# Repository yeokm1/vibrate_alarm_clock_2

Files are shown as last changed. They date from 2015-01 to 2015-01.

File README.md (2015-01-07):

vibrate_alarm_clock_2
===================

An alarm clock with vibration, battery monitoring and induction (wireless) charging capabilities.  Buttons available to set the time/alarm, turn off OLED and reset. This device is meant for my friend's birthday gift. 

As you can tell from the name, this is the second version. It has been slightly streamlined compared to the [first](https://github.com/yeokm1/vibrate_alarm_clock).

##Demo video on Youtube
(http://www.youtube.com/watch?v=rJnRN-2LL7Q)

##Final pictures
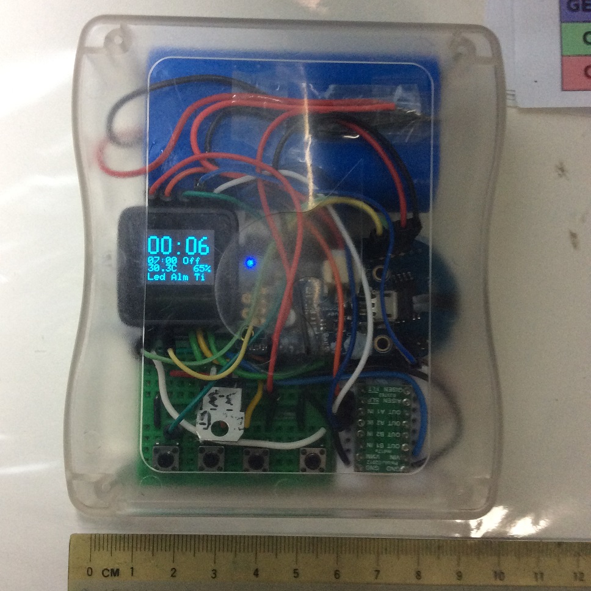
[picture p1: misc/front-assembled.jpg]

Front, fully assembled.

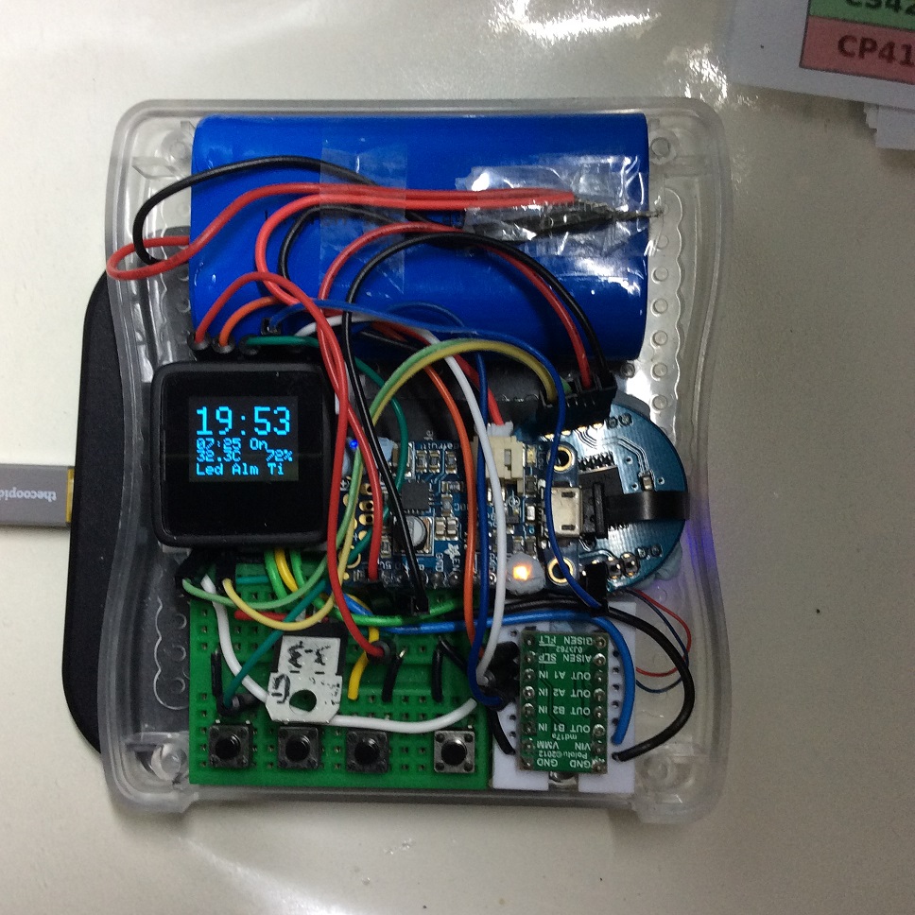
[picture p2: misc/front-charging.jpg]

Top cover removed and charging on my Qi wireless charge pad.

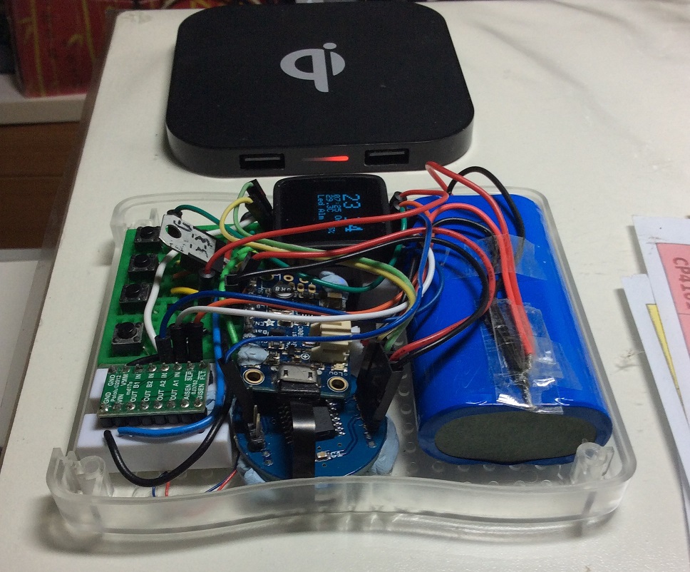
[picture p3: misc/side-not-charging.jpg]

Side view with top open. A Qi wireless charger in the background. Not so messy this time.

<b>More pictures during the assembly/testing phase at the end.</b>

##Parts used
1. [Microview](https://www.sparkfun.com/products/12923) with 64x48 OLED screen (based on ATmega328P chip). Bought during its Kickstarter [campaign](https://www.kickstarter.com/projects/1516846343/microview-chip-sized-arduino-with-built-in-oled-di).
2. [Chronodot](http://docs.macetech.com/doku.php/chronodot_v2.0) v2.1 Real Time Clock (based on DS3231 temperature compensated RTC crystal)
3. [Adafruit PowerBoost 500 Charger](https://learn.adafruit.com/adafruit-powerboost-500-plus-charger/overview)
4. 3.3V voltage regulator (LD1117V33)
5. 4x button switches (1 switch as reset button)  
6. [Pololu DRV8833](http://www.pololu.com/product/2130) dual motor driver  
7. 500mA Qi wireless receiver module
8. 10mm vibration motor
9. 4400mAh Lithium battery

Others:  

1. 1x half-breadboard 
2. 4x mini-breadboard (2x8 points)
3. Translucent case  

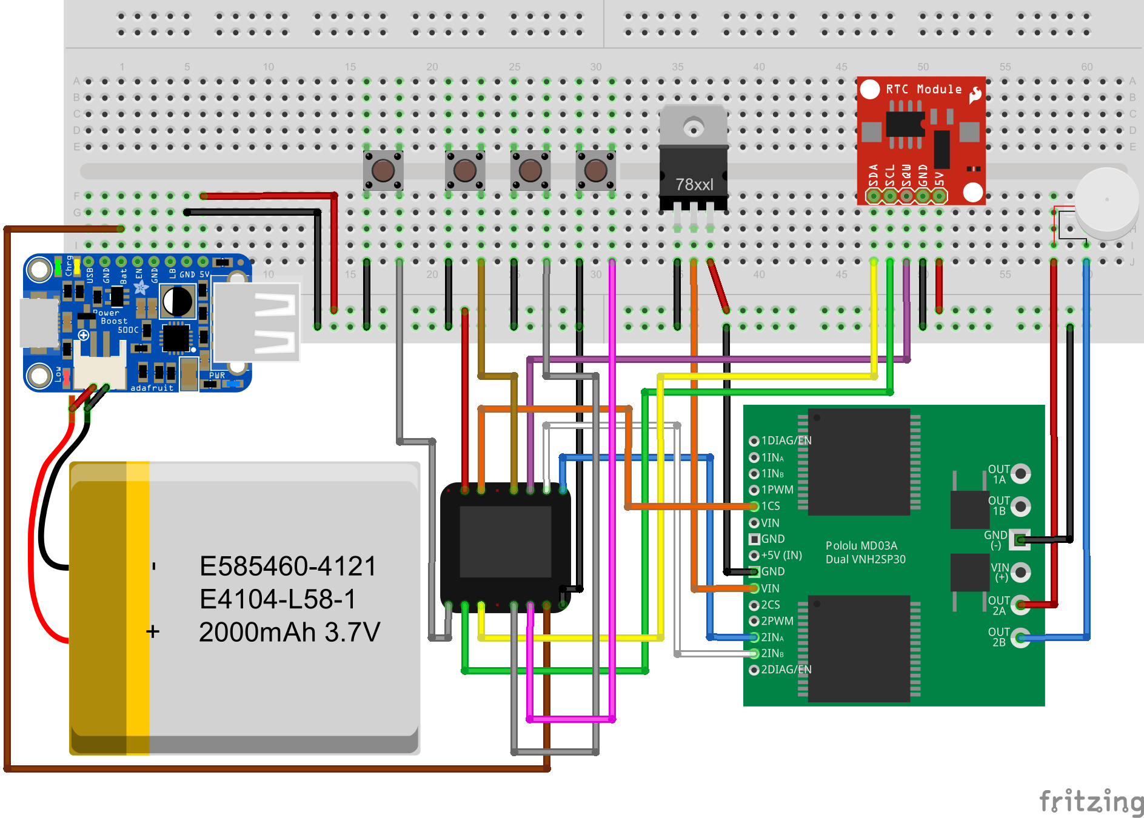
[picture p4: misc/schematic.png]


This schematic only represents the logical connections I made. The physical connections differs due to space issues.
Closest components used as Fritzing does not have them.

1. MD030A as DRV8833 motor driver. (Pin 6 on the Microview is connected to the sleep pin on the DRV8833.)
2. RTC module as Chronodot
3. The battery is a cylindrical style 4400mAh one.

##Differences with [version 1 (V1)](https://github.com/yeokm1/vibrate_alarm_clock)
1. No more pull-down resistors for the switches. I use the internal pull-up resistors of the Arduino by setting pinmode to INPUT_PULLUP.
2. Battery capacity: The battery size was an afterthought in V1. The battery size is now more than 4x larger.
3. Power consumption: Reduced by putting the Arduino to sleep and only waking via alarm interrupts from the Chronodot or button press. Even if alarm is enabled, current use is 34mA with display on and 16mA when in sleep giving battery life at approximately 5 and 11 days respectively. (See pictures below)
4. The components here now run at 5V levels instead of 3.3V previously as that is the output of the PowerBoost charger even though this may not be entirely efficient. I can't use the battery output directly as that value can drop below 3.3V.
5. The Pololu DRV8833 motor driver is powered behind a 3.3V regulator as 5V is too high for the 10mm vibration motor.
6. Display the temperature of the Chronodot.
7. Qi wireless charging. Frequent plugging in and out of the micro-USB cable may wear-out/damage the connector. Wireless charging is convenient too!
8. Removed speaker as it is rather soft. Even the vibration motor is louder than the speaker!

##Notes
1. The Analog to Digital Converter (ADC) of the Microview is rather unstable. As the battery voltage is retrieved via the ADC, I had to do a running average to get a stable value to display.

##Pictures during assembly/testing
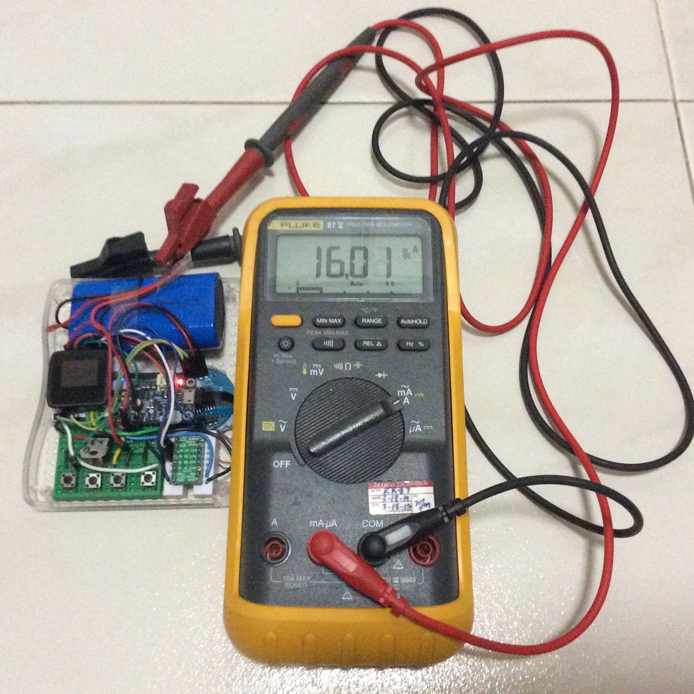
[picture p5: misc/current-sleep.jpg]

Current while in sleep mode. Hardware folks may say I can do better but I don't really have time to optimise so much.

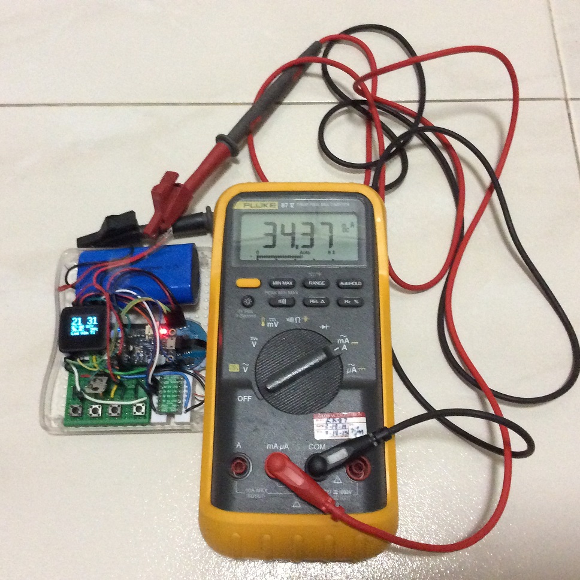
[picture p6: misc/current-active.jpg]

Current with screen on and no sleep. Current usage more than doubles.

Screen
Side profile. Obviously not charging at such distance away.

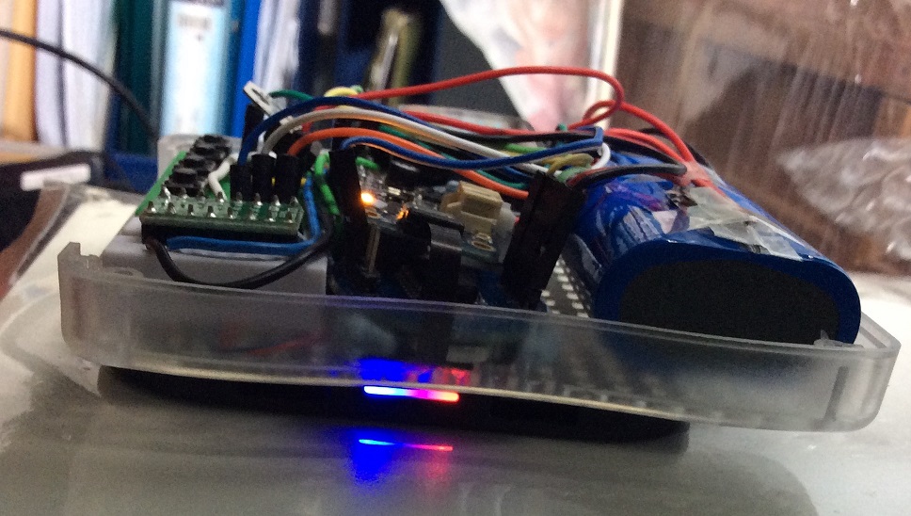
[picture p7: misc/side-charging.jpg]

On my Qi wireless charge pad. Blue light on the Qi pad and orange on the PowerBoost charger indicates a successful power transfer process.

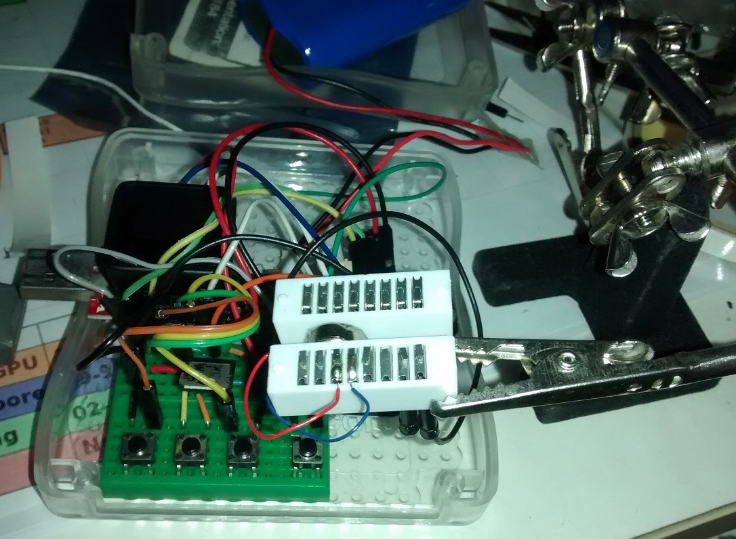
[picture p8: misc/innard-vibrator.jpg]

Under the motor driver is where I "hide" the vibrator to prevent it from jumping out of place as experienced in V1.

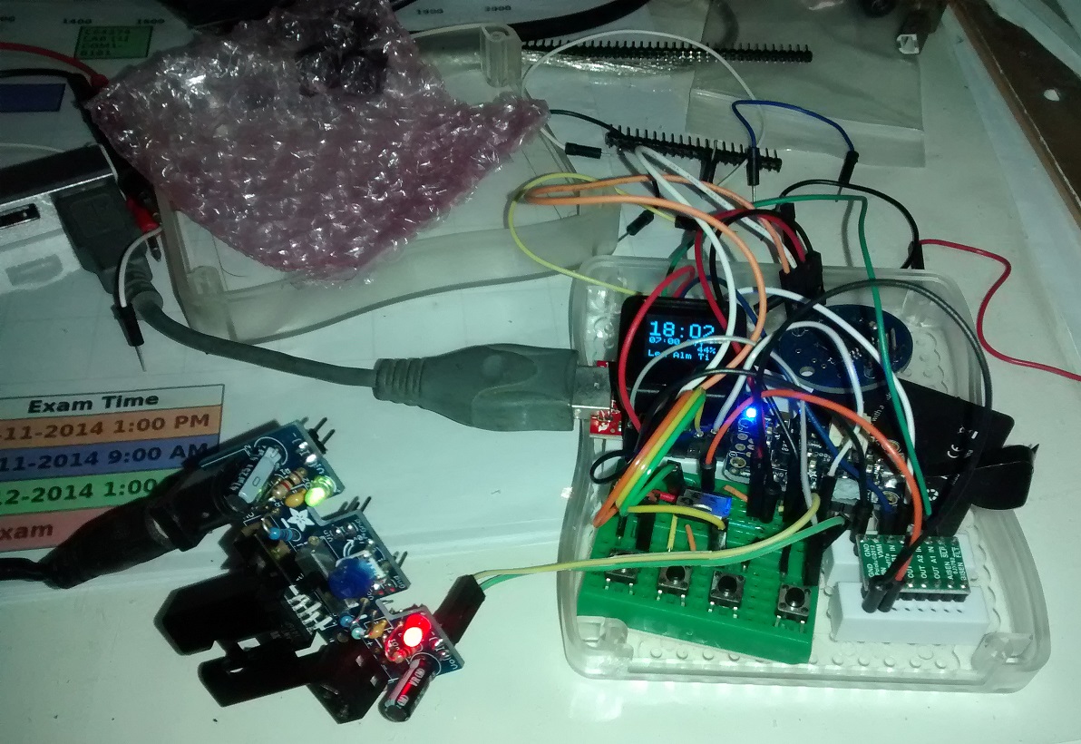
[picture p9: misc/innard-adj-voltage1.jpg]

I use the very nifty [adjustable voltage generator](https://learn.adafruit.com/adjustable-breadboard-power-supply-kit) to simulate a battery at different voltage levels to verify the battery percent readings.

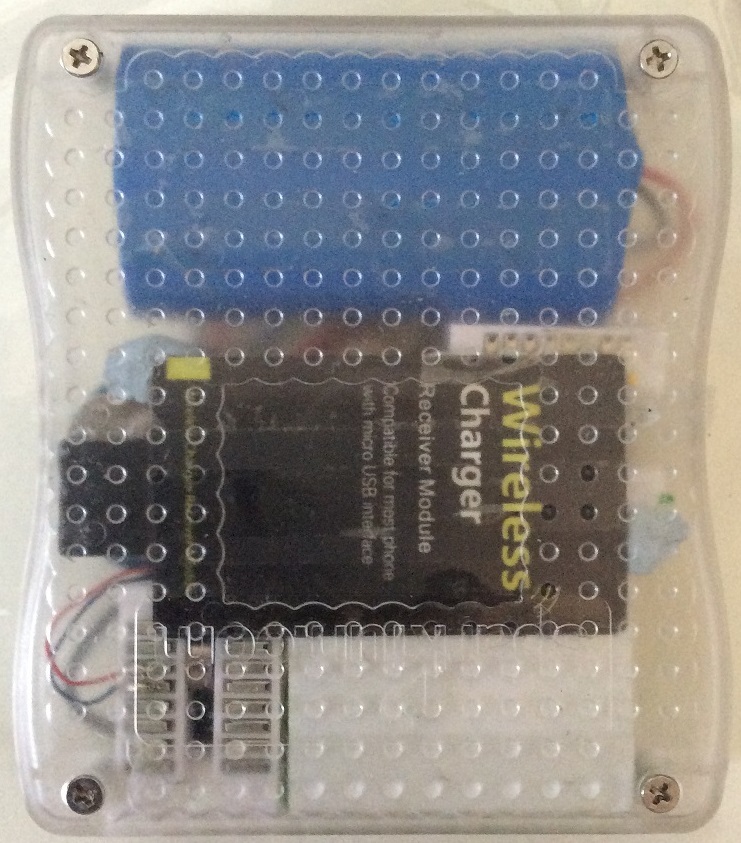
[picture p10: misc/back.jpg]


Adding a wireless power receiving capability is just as simple as adding a receiver pad. Why didn't I consider this earlier?

##References and libraries
1. [Creating fonts for Microview](http://learn.microview.io/font/creating-fonts-for-microview.html)
2. [DS3232 RTC library](https://github.com/JChristensen/DS3232RTC)
3. [Rocketscream Low Power library](http://www.rocketscream.com/blog/2011/07/04/lightweight-low-power-arduino-library/)

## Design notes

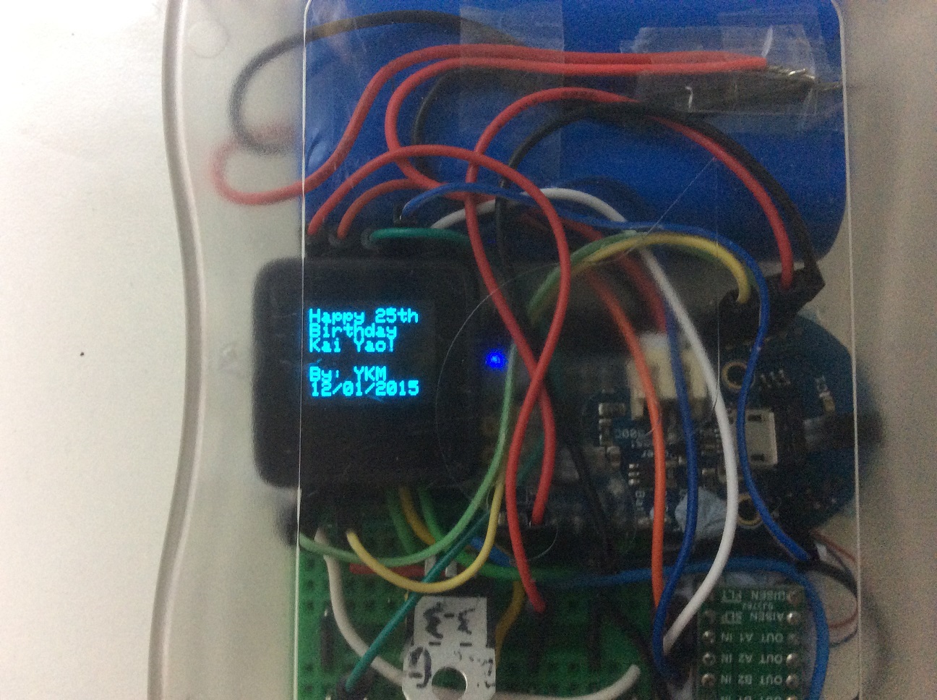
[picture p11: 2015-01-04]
misc/birthday.jpg

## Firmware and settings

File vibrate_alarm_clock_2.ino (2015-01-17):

#include <Wire.h>
#include <MicroView.h>
#include <DS3232RTC.h>
#include <Time.h>

#include "LowPower.h"

//These two refer to the same pin
#define LEFT_BUTTON_INT_PIN INT1
#define LEFT_BUTTON_NORM_PIN 3

#define MIDDLE_BUTTON_PIN A2
#define RIGHT_BUTTON_PIN A1

//These two refer to the same pin
#define ALARM_INT_PIN INT0//Driven LOW by Chronodot on alarm triggered
#define ALARM_NORM_PIN 2//Driven LOW by Chronodot on alarm triggered

#define VOLTAGE_MEASURE_PIN A0

#define MOTOR_PIN1 1
#define MOTOR_PIN2 0
#define MOTOR_SLEEP_PIN 6

#define ADC_PRECISION 1024

//You may need to calibrate these values. My values are based on this data sheet http://www.adafruit.com/datasheets/18650%204400mAh.pdf
#define MIN_BATTERY_MILLIVOLT 3100 //Discharge cut-off voltage is 2750 but I set it higher as repeated discharge to this low will reduce battery lifespan
#define MAX_BATTERY_MILLIVOLT 4200 //Max cell voltage

#define MIN_TIME_BETWEEN_BUTTON_PRESSES 150  //Debouncing purposes

#define MAX_ALARM_LENGTH 600000 //Alarm rings for 10 minutes max


#define BLINK_INTERVAL_SETTINGS 100
#define BLINK_INTERVAL_SECONDS 500

#define MIN_TIME_BETWEEN_ALARM_STARTS 60000 //60 seconds
#define MIN_TIME_BETWEEN_MOTOR_STATES 500

#define INITIAL_TEXT "Happy 25thBirthday\nKai Yao!\n\nBy: YKM\n12/01/2015"
#define INITIAL_TEXT_DELAY 5000

#define TIME_BEFORE_STANDBY 10000 //10s

typedef enum {
  NORMAL, ALARM, SETTING_TIME, SETTING_ALARM} 
CLOCK_STATE ;
volatile CLOCK_STATE currentState = NORMAL;

typedef enum {
  T_HOUR, T_MINUTE, T_VOLTAGE} 
SETTING_TIME_STATE ;
SETTING_TIME_STATE settingTimeProcess;

typedef enum {
  A_HOUR, A_MINUTE, A_TYPE} 
SETTING_ALARM_STATE ;
SETTING_ALARM_STATE settingAlarmProcess;

int alarmHour = 07;
int alarmMinute = 00;

unsigned long alarmLastStarted;

unsigned long timeLastPressedLeftButton;
unsigned long timeLastPressedMiddleButton;
unsigned long timeLastPressedRightButton;

boolean vibrate = false;
boolean showVoltage = false;

boolean previousBlinkState;
unsigned long previousBlinkTime;

boolean previousSecondsBlinkState;
unsigned long previousSecondsBlinkTime;

volatile boolean showLCD = true;
unsigned long lastVibration;
boolean lastMotorState = false;


const int numReadings = 40;

int percentReadings[numReadings];
int percentIndex = 0;    
long percentTotal = 0; 

int milliVoltReadings[numReadings];
int milliVoltIndex = 0;     
long milliVoltTotal = 0;     

long lastScreenActiveTime = 0;

void setup() {

  Wire.begin();
  //Serial.begin(9600);

  setSyncProvider(RTC.get);

  //Clear prior alarm settings on reload
  RTC.squareWave(SQWAVE_NONE);
  RTC.alarmInterrupt(ALARM_1, false);  
  RTC.alarmInterrupt(ALARM_2, false);



  uView.begin();      // begin of MicroView
  uView.clear(ALL);   // erase hardware memory inside the OLED controller
  uView.contrast(0); //Lowest constrast so not so glaring

  pinMode(LEFT_BUTTON_NORM_PIN, INPUT_PULLUP);
  pinMode(MIDDLE_BUTTON_PIN, INPUT_PULLUP);
  pinMode(RIGHT_BUTTON_PIN, INPUT_PULLUP);

  pinMode(VOLTAGE_MEASURE_PIN, INPUT);

  pinMode(ALARM_NORM_PIN, INPUT_PULLUP);


  pinMode(MOTOR_PIN1, OUTPUT); 
  pinMode(MOTOR_PIN2, OUTPUT);
  pinMode(MOTOR_SLEEP_PIN, OUTPUT);

  motorDriverState(false);

  timeLastPressedLeftButton = 0;
  timeLastPressedMiddleButton = 0;
  timeLastPressedRightButton = 0;

  uView.clear(PAGE); 
  uView.setFontType(0);

  uView.println(INITIAL_TEXT); 

  uView.display();


  delay(INITIAL_TEXT_DELAY);
  attachInterrupt(ALARM_INT_PIN, alarmTriggered, FALLING);
  attachInterrupt(LEFT_BUTTON_INT_PIN, leftButtonIntPressed, FALLING); //Left Button is used to wake up from deep sleep
  
  lastScreenActiveTime = millis();
}

void loop (){


  int leftButtonState = digitalRead(LEFT_BUTTON_NORM_PIN);
  int middleButtonState = digitalRead(MIDDLE_BUTTON_PIN);
  int rightPinState = digitalRead(RIGHT_BUTTON_PIN);


  if(leftButtonState == LOW){
    processLeftButtonPressed();
  }

  if(middleButtonState == LOW){
    processMiddleButtonPressed();
  }

  if(rightPinState == LOW){
    processRightButtonPressed();
  }

  soundAlarmAtThisPointIfNeeded();
  
  long currentTime = millis();

  //Disable alarm if it has gone longer than maximum
  if(currentState == ALARM && (currentTime - alarmLastStarted) > MAX_ALARM_LENGTH){
    stopAlarm();
  }
  
  //Auto turn off screen after certain time
  if(currentState == NORMAL && showLCD && ((currentTime - lastScreenActiveTime) > TIME_BEFORE_STANDBY)){
    showLCD = false;
    turnOffLCDIfCommandIsOff();
  }

  if(showLCD || currentState == ALARM){
    setSyncProvider(RTC.get);

    uView.clear(PAGE);

    boolean blinkOn = shouldBlinkNow();
    boolean secondsBlink = shouldSecondsBlinkNow();

    int voltageADCReading = getVoltageADCReading();

    long vccVoltage = getVcc();
    //Serial.println(vccVoltage);
    int batteryMilliVolt = ((long) voltageADCReading * vccVoltage) / ADC_PRECISION;

    float celsius = RTC.temperature() / 4.0;


    writeTimeToDisplayBuffer(blinkOn, secondsBlink);
    writeAlarmToDisplayBuffer(blinkOn);




    writeVoltageAndTempToDisplayBuffer(batteryMilliVolt, celsius, blinkOn);
    writeButtonStateToDisplayBuffer(blinkOn);


    uView.display();
  }


  if(currentState == NORMAL){   
    if(showLCD){
      LowPower.powerDown(SLEEP_15Ms, ADC_OFF, BOD_OFF);
    }
    else {
      LowPower.powerDown(SLEEP_FOREVER, ADC_OFF, BOD_OFF);
    }

  }


}

int getVoltageADCReading(){
  return analogRead(VOLTAGE_MEASURE_PIN); 
}


void turnOffLCDIfCommandIsOff(){
  if(!showLCD){
    uView.clear(PAGE);
    uView.display();
  }
}

void leftButtonIntPressed(){
  if(!showLCD && currentState == NORMAL){
    showLCD = true;
    long currentTime = millis();
    timeLastPressedLeftButton = currentTime;
    lastScreenActiveTime = currentTime;
  }
}

void processLeftButtonPressed(){
  unsigned long currentMillis = millis();

  if((currentMillis - timeLastPressedLeftButton) < MIN_TIME_BETWEEN_BUTTON_PRESSES){
    return;
  }
  

  timeLastPressedLeftButton = currentMillis;
  lastScreenActiveTime = currentMillis;

  //Serial.println("Left Button Pressed");

  switch(currentState)
  {
  case ALARM: 
    stopAlarm();
    break;
  case NORMAL :
    {
      showLCD = !showLCD;
      turnOffLCDIfCommandIsOff();

    }
    break;
  case SETTING_ALARM:
    {
      if(settingAlarmProcess == A_HOUR){
        alarmHour = getNextHourFromCurrentHour(alarmHour, false);
      } 
      else if(settingAlarmProcess == A_MINUTE){
        alarmMinute = getNextMinSecFromCurrentMinSec(alarmMinute, false);
      } 
      else if(settingAlarmProcess == A_TYPE){
        vibrate = !vibrate;
      }

    }
    break;
  case SETTING_TIME:
    {
      switch(settingTimeProcess){
      case T_HOUR:
        setTime(getNextHourFromCurrentHour(hour(), false), minute(), second(), day(), month(), year());
        break;
      case T_MINUTE:
        setTime(hour(), getNextMinSecFromCurrentMinSec(minute(), false), second(), day(), month(), year());
        break;
      case T_VOLTAGE:
        showVoltage = !showVoltage;
        break;
      default: 
        break;

      }


      RTC.set(now()); 
    }
    break;
  default: 
    break;
  }


}

void processMiddleButtonPressed(){
  unsigned long currentMillis = millis();

  if((currentMillis - timeLastPressedMiddleButton) < MIN_TIME_BETWEEN_BUTTON_PRESSES){
    return;
  }

  timeLastPressedMiddleButton = currentMillis;
  lastScreenActiveTime = currentMillis;

  //Serial.println("Middle Button Pressed");

  switch(currentState)
  {
  case ALARM: 
    stopAlarm();
    break;
  case NORMAL :
    {
      if(showLCD){
        currentState = SETTING_ALARM;
        settingAlarmProcess = A_HOUR;
      } 
      else {
        showLCD = true;
      }

    }
    break;
  case SETTING_ALARM:
    {
      if(settingAlarmProcess == A_HOUR){
        settingAlarmProcess = A_MINUTE;
      } 
      else if(settingAlarmProcess == A_MINUTE){
        settingAlarmProcess = A_TYPE;
      } 
      else {
        if(vibrate){
          RTC.alarm(ALARM_2); //Reset existing alarm
          RTC.setAlarm(ALM2_MATCH_HOURS, alarmMinute, alarmHour, 0);
          RTC.alarmInterrupt(ALARM_2, true);
        } 
        else{
          RTC.alarmInterrupt(ALARM_2, false);
        }
        currentState = NORMAL;
      }

    }
    break;
  case SETTING_TIME:
    {
      if(settingTimeProcess == T_HOUR){
        settingTimeProcess = T_MINUTE;
      } 
      else if(settingTimeProcess == T_MINUTE){
        settingTimeProcess = T_VOLTAGE;
      }
      else {
        currentState = NORMAL;
      }

    }
    break;
  default: 
    break;
  }


}

void processRightButtonPressed(){
  unsigned long currentMillis = millis();


  if((currentMillis - timeLastPressedRightButton) < MIN_TIME_BETWEEN_BUTTON_PRESSES){
    return;
  }

  timeLastPressedRightButton = currentMillis;
  lastScreenActiveTime = currentMillis;

  //Serial.println("Right Button Pressed");


  switch(currentState)
  {
  case ALARM: 
    stopAlarm();
    break;
  case NORMAL :
    { 
      if(showLCD){
        currentState = SETTING_TIME;
        settingTimeProcess = T_HOUR;
      } 
      else {
        showLCD = true;
      }

    }
    break;
  case SETTING_ALARM:
    {
      if(settingAlarmProcess == A_HOUR){
        alarmHour = getNextHourFromCurrentHour(alarmHour, true);
      } 
      else if(settingAlarmProcess == A_MINUTE){
        alarmMinute = getNextMinSecFromCurrentMinSec(alarmMinute, true);
      } 
      else if(settingAlarmProcess == A_TYPE){
        vibrate = !vibrate;
      }

    }
    break;
  case SETTING_TIME:
    {
      switch(settingTimeProcess){
      case T_HOUR:
        setTime(getNextHourFromCurrentHour(hour(), true), minute(), second(), day(), month(), year());
        break;
      case T_MINUTE:
        setTime(hour(), getNextMinSecFromCurrentMinSec(minute(), true), second(), day(), month(), year());
        break;
      case T_VOLTAGE:
        showVoltage = !showVoltage;
        break;
      default: 
        break;

      }

      RTC.set(now()); 
    }


    break;
  default: 
    break;
  }

}


void alarmTriggered(){

  if(currentState == NORMAL && currentState != ALARM){
    alarmLastStarted = millis();
    currentState = ALARM;
    motorDriverState(true);
  }
}


void soundAlarmAtThisPointIfNeeded(){
  if(currentState == ALARM){

    unsigned long currentMillis = millis();
    if((currentMillis - lastVibration) > MIN_TIME_BETWEEN_MOTOR_STATES){
      lastVibration = currentMillis;

      if(lastMotorState){
        lastMotorState = false;
        changeMotorState(false, false);
      } 
      else {
        lastMotorState = true;
        changeMotorState(true, true);
      }


    }


  }


}



void stopAlarm(){
  RTC.alarm(ALARM_2);
  currentState = NORMAL;
  motorDriverState(false); 
  turnOffLCDIfCommandIsOff();
}

void motorDriverState(boolean state){

  if(state){
    digitalWrite(MOTOR_SLEEP_PIN, HIGH);
  } 
  else {
    digitalWrite(MOTOR_SLEEP_PIN, LOW);
  }
}

void changeMotorState(boolean active, bool direction){

  if(!active){
    digitalWrite(MOTOR_PIN1, LOW);
    digitalWrite(MOTOR_PIN2, LOW);
    return; 
  }

  if(direction){
    digitalWrite(MOTOR_PIN1, HIGH);
    digitalWrite(MOTOR_PIN2, LOW);     
  } 
  else {
    digitalWrite(MOTOR_PIN1, LOW);
    digitalWrite(MOTOR_PIN2, HIGH); 
  }



}

void writeTimeToDisplayBuffer(boolean blinkOn, boolean secondsBlinkOn){
  uView.setCursor(0,0);
  uView.setFontType(7);

  String timeString = generateTimeString(hour(), minute(), blinkOn, secondsBlinkOn);
  uView.println(timeString);
}

String generateTimeString(int hour, int minute, boolean blinkOn, boolean secondsBlinkOn){
  char buff[3];

  String hourString;

  if(currentState == SETTING_TIME && settingTimeProcess == T_HOUR && !blinkOn){
    hourString = "  ";
  } 
  else {
    sprintf(buff, "%02d", hour);
    hourString = buff;
  }

  String minuteString;
  if(currentState == SETTING_TIME && settingTimeProcess == T_MINUTE && !blinkOn){
    minuteString = "  ";
  } 
  else {
    sprintf(buff, "%02d", minute);
    minuteString = buff;
  }

  String secondString;

  if(secondsBlinkOn || currentState == SETTING_TIME){
    secondString = ":";
  } 
  else {
    secondString = " ";
  }


  String result = hourString + secondString + minuteString;

  return result;
}

void writeAlarmToDisplayBuffer(boolean blinkOn){
  uView.setFontType(0);
  uView.setCursor(0,24);

  char buff[3];

  String alarmHourString;

  if(currentState == SETTING_ALARM && settingAlarmProcess == A_HOUR && !blinkOn){
    //Now setting this, do not show 
    alarmHourString = "  ";
  } 
  else {
    sprintf(buff, "%02d", alarmHour);
    alarmHourString = buff;
  }

  String alarmMinuteString;

  if(currentState == SETTING_ALARM && settingAlarmProcess == A_MINUTE && !blinkOn){
    //Now setting this, do not show 
    alarmMinuteString = "  ";
  } 
  else {
    sprintf(buff, "%02d", alarmMinute);
    alarmMinuteString = buff;
  }

  String alarmTimeString;
  String alarmSetting;

  if(currentState == SETTING_ALARM && settingAlarmProcess == A_TYPE && !blinkOn){
    //Now setting this, do not show 
    alarmSetting = "";
  } 
  else {
    if(vibrate){
      alarmSetting = " On"; 
    }
    else {
      alarmSetting = " Off";
    }
  }

  alarmTimeString = alarmHourString + ":" + alarmMinuteString + alarmSetting;

  uView.print(alarmTimeString);

}


int getNewAverageReadingFromCurrentReading(int array[], int * index, long * total, int numReadings, int newReading){
  *total = *total - array[*index];
  array[*index] = newReading; 
  *total = *total + array[*index];    

  *index = *index + 1;                    


  if (*index >= numReadings) {
    *index = 0;                           
  }
  int average =  *total / numReadings;  
  return average;
}

void writeVoltageAndTempToDisplayBuffer(int batteryMilliVolt, float temperature, boolean blinkOn){
  uView.setFontType(0);
  uView.setCursor(0,32);

  batteryMilliVolt = getNewAverageReadingFromCurrentReading(milliVoltReadings, &milliVoltIndex, &milliVoltTotal, numReadings, batteryMilliVolt);
  float voltage = (float) batteryMilliVolt / 1000;

  char buff[6];
  String tempString = dtostrf(temperature, 4, 1, buff);

  uView.print(tempString);
  uView.print("C");

  int batteryRange = MAX_BATTERY_MILLIVOLT - MIN_BATTERY_MILLIVOLT;

  //Cast to long as Arduino int is only 16 bits wide. Not enough to hold this result
  long numerator =  ((long) ((batteryMilliVolt - MIN_BATTERY_MILLIVOLT))) * 100;

  if(currentState != SETTING_TIME || settingTimeProcess != T_VOLTAGE || blinkOn){

    if(showVoltage){
        uView.setCursor(35,32);
        float batteryVolt = batteryMilliVolt / 1000.0;
        uView.print(batteryVolt);
        uView.print("V");
    } 
    else {

      int batteryPercent = numerator / batteryRange;


      batteryPercent = getNewAverageReadingFromCurrentReading(percentReadings, &percentIndex, &percentTotal, numReadings, batteryPercent);

      if(batteryPercent < 0 || batteryPercent >= 100){
        uView.setCursor(35,32);
      } 
      else {
        uView.setCursor(47,32);
      }

      uView.print(batteryPercent);
      uView.print("%");
    }
  }
}

void writeButtonStateToDisplayBuffer(boolean blinkOn){
  uView.setFontType(0);
  uView.setCursor(0,41);

  String buttonFunction;
  switch(currentState)
  {
  case ALARM: 
    {
      if(!blinkOn){
        buttonFunction = "X   X   X";
      }

    }
    break;
  case NORMAL : 
    buttonFunction =  "Led Alm Ti";
    break;
  case SETTING_ALARM: 
    //Fallthrough
  case SETTING_TIME: 
    buttonFunction = "-  Next  +";
    break;
  default: 
    break;
  }

  uView.print(buttonFunction);
}


boolean shouldBlinkNow(){
  unsigned long currentMillis = millis();

  if(currentMillis - previousBlinkTime >  BLINK_INTERVAL_SETTINGS) {
    previousBlinkTime = currentMillis;   
    previousBlinkState = !previousBlinkState;
  }
  return previousBlinkState;
}


boolean shouldSecondsBlinkNow(){
  unsigned long currentMillis = millis();

  if(currentMillis - previousSecondsBlinkTime >  BLINK_INTERVAL_SECONDS) {
    previousSecondsBlinkTime = currentMillis;   
    previousSecondsBlinkState = !previousSecondsBlinkState;
  }
  return previousSecondsBlinkState;
}

//Access secret voltmeter for Analog reference comparison
//  https://code.google.com/p/tinkerit/wiki/SecretVoltmeter
long getVcc() {
  long result;
  // Read 1.1V reference against AVcc
  ADMUX = _BV(REFS0) | _BV(MUX3) | _BV(MUX2) | _BV(MUX1);
  delay(2); // Wait for Vref to settle
  ADCSRA |= _BV(ADSC); // Convert
  while (bit_is_set(ADCSRA,ADSC));
  result = ADCL;
  result |= ADCH<<8;
  result = 1126400L / result; // Back-calculate AVcc in mV


  return result;
}


int getNextHourFromCurrentHour(int current, boolean increment){
  int change;
  if(increment){
    change = 1;
  } 
  else {
    change = -1;
  }

  int newValue = current + change;

  //To produce positive modulo result
  return (newValue % 24 + 24) % 24;
}

int getNextMinSecFromCurrentMinSec(int current, boolean increment){
  int change;
  if(increment){
    change = 1;
  } 
  else {
    change = -1;
  }

  int newValue = current + change;

  //To produce positive modulo result
  return (newValue % 60 + 60) % 60;
}

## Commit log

2015-01-02 copying of button functions
2015-01-02 button function text
2015-01-02 pinmode of motor pins
2015-01-03 low power and libraries
2015-01-04 sync time only within showLCD. Reset existing alarm before setting new one
    [vibrate_alarm_clock_2.ino]
2015-01-04 remove need to use pull up resistor for interrupt
2015-01-04 write temperature to display
2015-01-04 battery percent position
2015-01-04 disable serial to free up pins 0 and 1 for motor
2015-01-04 left button pin to wake up from deep sleep
2015-01-04 minimum cut off voltage at 2600mV
2015-01-04 put motor drive to sleep on start
2015-01-04 slight change
    [schematic.fzz]
2015-01-07 reduce battery min voltage
2015-01-07 show battery voltage instead of percent
